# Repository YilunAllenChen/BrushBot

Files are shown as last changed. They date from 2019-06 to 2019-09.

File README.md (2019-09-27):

# BrushBot 2

This Repo serves the BrushBot 2.0 project from its hardware to its software.

## Project Structure
main.py: the program that ESP will execute once it boots up.\
ina219.py: Firmware for ina219 current sensor.\
vl6180Driver.py: Firmware for VL6180x sensor.\
logging.py: Supporting module for ina219 current sensor.\
DRV8836.py: Firmware for DRV8836 motor driver.

## Installation
Before the installation process begins, make sure your BrushBot is connected through FTDI to the computer.

You need to find the port connected to the BrushBot and replace "your_port" in the script below with that port. on Windows it should look like "COMx", mac "dev/xxxxx", linux "USB/ttyx".

Then run the script under the repo directory:

    python install.py your_port

The script provided by this repo will allow you to automatically install the dependencies of computer-brushbot interaction. Afterwards, it will attempt to installing the micropython firmware under the ./_MicroPython_bin directory to the BrushBot connected. This process involves erasing the flash and putting the bin file inside.

Once this is done, you can use the following script to automatically upload all your programs under ./Firmware directory to the robot. The your_port part is the same deal as the one with the install.py script.

    python Upload.py your_port

## INA219 Interface Example

```python
from ina219 import INA219
from machine import I2C

i2c = machine.I2C(-1,machine.Pin(22),machine.Pin(21)) #setup i2c
SHUNT_OHMS = 0.1 # Hardware setup - shunt resistance
ina = INA219(SHUNT_OHMS, i2c) # Create a sensor object
ina.configure() # Default configuration

# Usage
print("Bus Voltage: %.3f V" % ina.voltage())
print("Current: %.3f mA" % ina.current())
print("Power: %.3f mW" % ina.power())
```

## VL6180 Interface Example

```python
import machine
import sys
import utime
import vl6180_Driver

i2c = machine.I2C(-1,machine.Pin(22),machine.Pin(21)) #setup i2
sensor1 = vl6180_Driver.Sensor(i2c,41) # Create a sensor object

# Usage
print("Value read in address 41: " + str(sensor1.range()))
```

## DRV8836 Interface Example

```python
import machine #Required by machine.Pin
import DRV8836

A1 = machine.Pin(33) # Select the four pins used to control
A2 = machine.Pin(25) # the two motors
B1 = machine.Pin(26)
B2 = machine.Pin(27)
drv = DRV8836.DRV8836(A1, A2, B1, B2) # Create the motor driver object

# Usage
drv.testRun() # Test run function.
drv.setLeft(1000) # Set the motor output of left. -1023 ~ 1023.
drv.stop()
```

## TCP-IP
Note: In order for the Controller to work, the server side computer needs to allow TCP/IP inbound/outbound connections on port 23.

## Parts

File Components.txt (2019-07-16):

VL6180	-	Light Sensor
ESP32 -	MCU
AP2112	-	Voltage Regulator / Power supply
BQ24075 -	Wireless Charging
	Choosing charging rates:
		K_ISET values: min/avg/max: 797/890/975
		I_CHG => K_ISET/R_ISET. For example, In order to have a 800mA charge current: 890 / 0.8 = 1.1125kOhm, so connect a 1.13kOhm resistor between ISET(16) and VSS.

	Choosing Limit charge rates:
		K_ILIM values: min/avg/max: 1550/1610/1720 for I_LIM in (0.5A,1.5A), 1330/1525/1720 for I_LIM in (0.2A, 0.5A). I_LIM at pin 12.
		R_ISET = 1550 / 1.3 = 1.192kOhm, so connect a 1.18kOhm resistor between ILIM(12) and VSS.

	Choosing 6.25h safety charging timer:
		R_TMR = t_maxchrg / (10*K_TMR)
		K_TMR = 48 (36/48/60)
		R_TMR = 6.25h * 3600s/h / (10*48) = 46.8kOhm, so connect a 46.4kOhm between TMR(2) and VSS.

INA219 - 	Current Sensor / Power monitoring component

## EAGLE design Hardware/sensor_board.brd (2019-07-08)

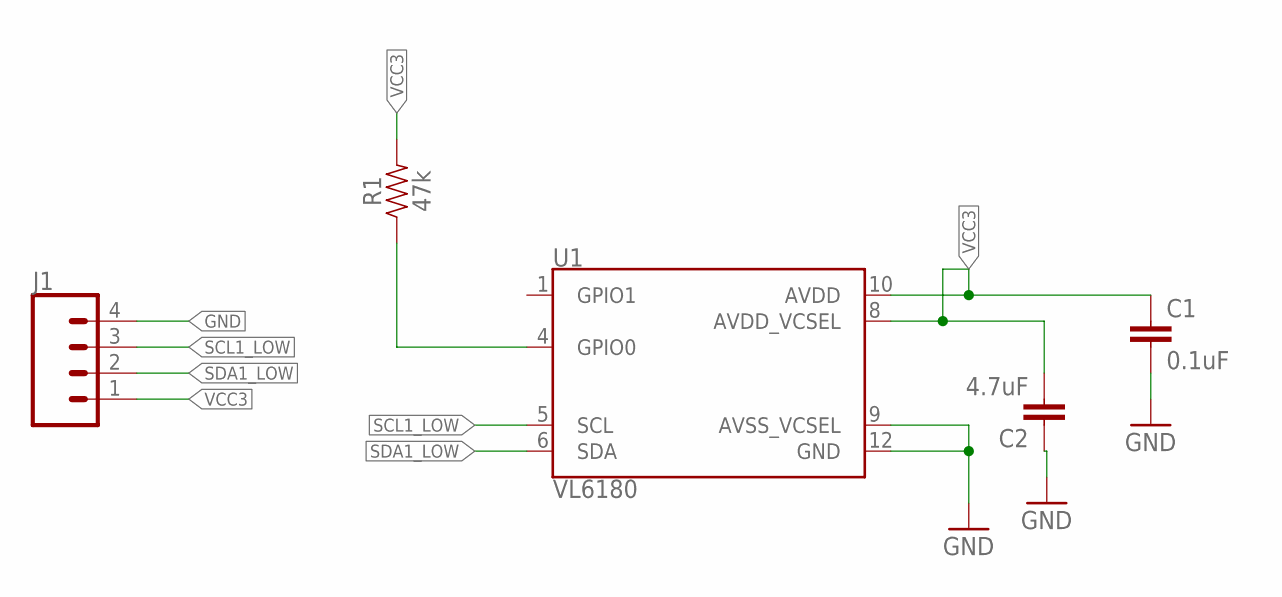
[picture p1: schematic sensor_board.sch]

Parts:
C1: 0.1uF; 0603
C2: 4.7uF; 0603
J1: CONN_04PTH; 1X04
R1: 47k; 0603
U1: VL6180

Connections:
GND: C1.2, C2.1, J1.4, U1.9 (AVSS_VCSEL), U1.12 (GND)
unnamed: R1.1, U1.4 (GPIO0)
SCL1_LOW: J1.3, U1.5 (SCL)
SDA1_LOW: J1.2, U1.6 (SDA)
VCC3: C1.1, C2.2, J1.1, R1.2, U1.8 (AVDD_VCSEL), U1.10 (AVDD)

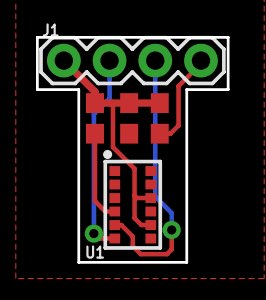
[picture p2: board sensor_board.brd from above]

Board: 2 copper layers, 10.6 x 12.5 mm, 5 parts (0 on the bottom side), 5 nets.

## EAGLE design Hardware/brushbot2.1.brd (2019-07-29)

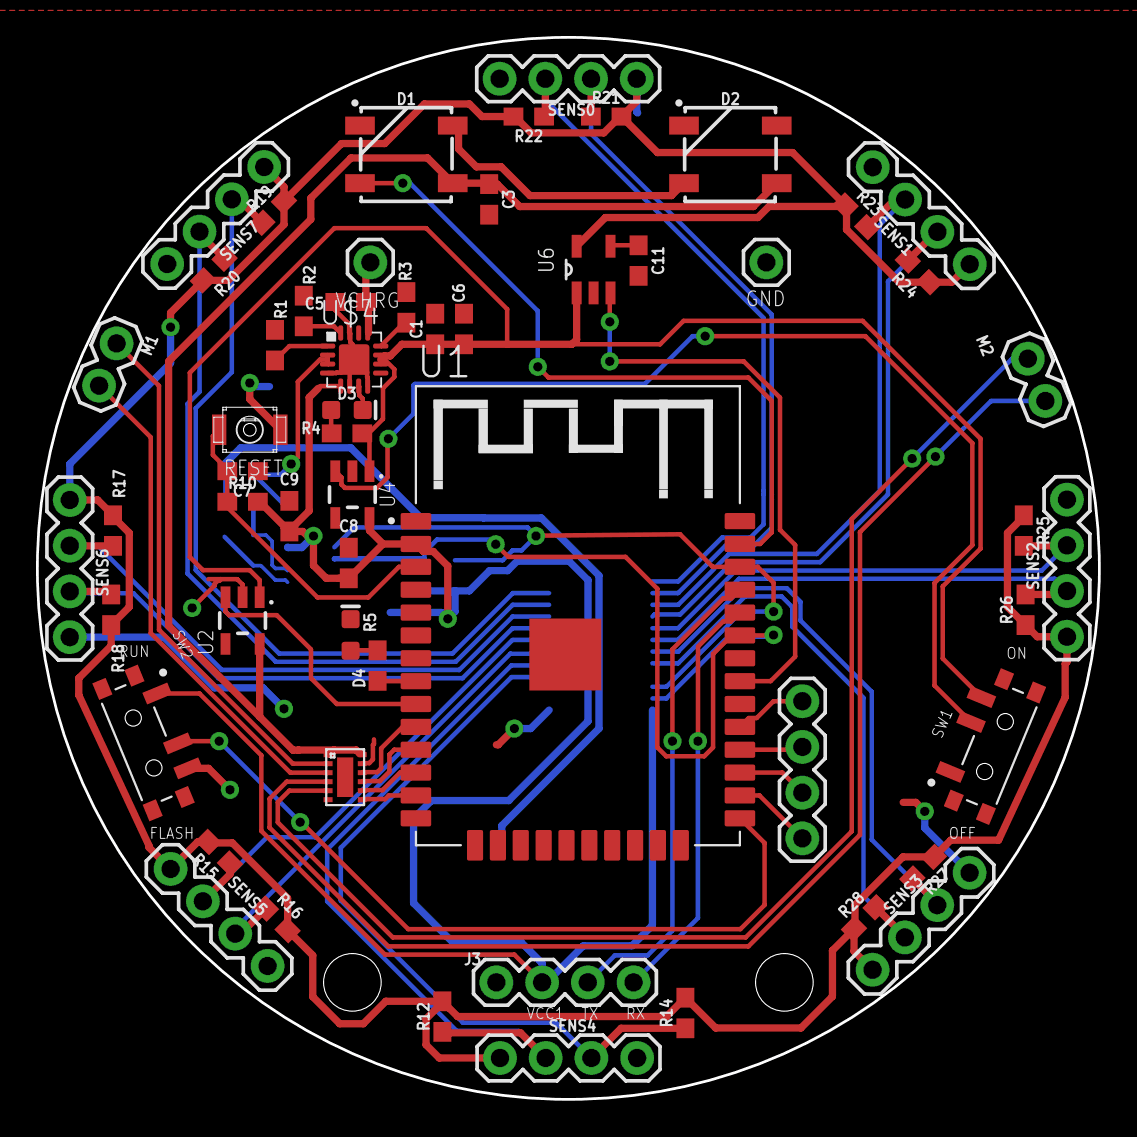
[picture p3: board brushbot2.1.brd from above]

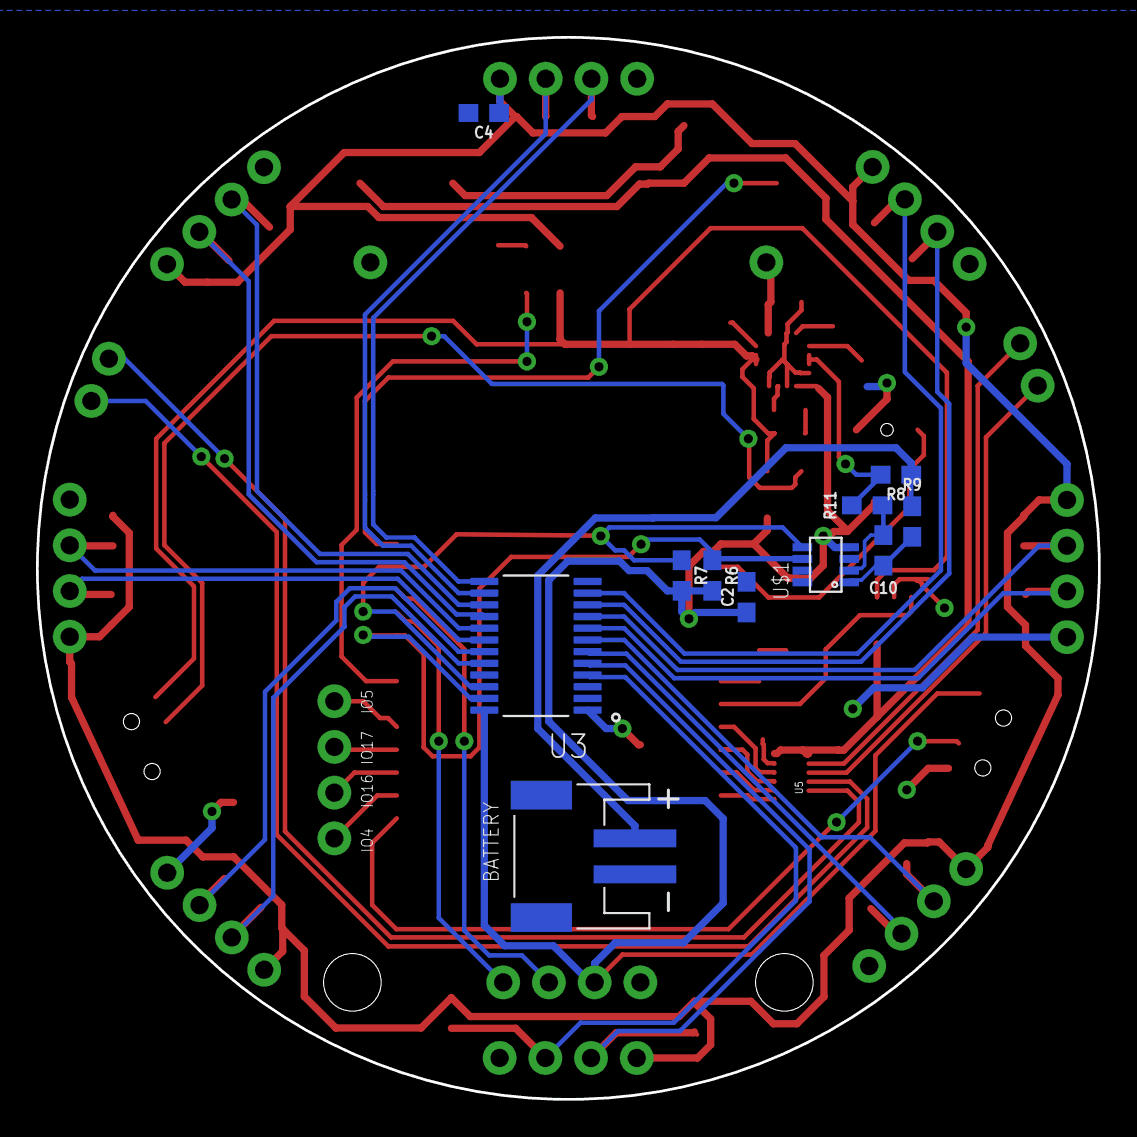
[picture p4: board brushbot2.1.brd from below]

Board: 2 copper layers, 59.0 x 59.0 mm, 69 parts (11 on the bottom side), 57 nets.

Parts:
C1, C2, C3, C5: 1.0uF; 0603
C4: 10uF; 0603
C6: 4.7uF; 0603
C7, C8, C9, C10: 0.1uF; 0603
C11: 10nF; 0603
CN1: JST-PH-2-SMT-RA
D1, D2: WS2812B
D3, D4: RED; LED-0603
FRAME2: FRAME-LEDGER; CREATIVE_COMMONS
J3, J12: 1X04
J4, J5: 1X01
M1, M2: 1X02
R1, R10: 10k; 0603
R2: 1.8k; 0603
R3, R4: 1k; 0603
R5: 47k; 0603
R6, R7, R12, R14, R15, R16, R17, R18, R19, R20, R21, R22, R23, R24, R25, R26, R27, R28: 4.7k; 0603
R8: 0.05; 0603
R9, R11: 10; 0603
RST_BUTTON: BUTTON_TACTILE_SLIM
SENS0, SENS1, SENS2, SENS3, SENS4, SENS5, SENS6, SENS7: 1X04
SW1, SW2: PCM12SMTR; SW_PCM12SMTR
U1: ESP-WROOM-32; MODULE_ESP-WROOM-32
U2, U4: 3.3V; SOT23-5
U3: TCA9548APWR; SOP65P640X120-24N
U5: DRV8836; 12WSON
U6: TPS79328DBVR; SOT95P280X145-5N
U$1: INA219; SOT-23-8
U$4: BQ24075; QFN16

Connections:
26: J12.1, U1.26
27: J12.2, U1.27
28: J12.3, U1.28
29: J12.4, U1.29
AIN1: U1.10, U5.10
AIN2: U1.11, U5.9
BIN1: U1.12, U5.8
BIN2: U1.13, U5.7
GND: C1.2, C2.2, C3.2, C4.2, C5.2, C6.2, C7.1, C8.1, C9.1, C11.2, CN1.2, D1.3, D2.3, D4.C, J3.1, J5.1, R1.1, R2.1, R3.2, RST_BUTTON.2, SENS0.4, SENS1.4, SENS2.4, SENS3.4, SENS4.4, SENS5.4, SENS6.4, SENS7.4, SW1.1, SW2.3, U1.1, U1.1.1, U1.15, U1.38, U2.2, U3.1, U3.2, U3.12, U3.21, U4.2, U5.6, U5.11, U6.2, U$1.3, U$1.7, U$1.8, U$4.4, U$4.6, U$4.8, U$4.15, U$4.TH
GPIO0: SW2.2, U1.25
LED1OUT: D1.2, D2.4
LEDS: D1.4, U1.37
M1+: M1.1, U5.2
M1-: M1.2, U5.3
M2+: M2.1, U5.4
M2-: M2.2, U5.5
MOTOR_EN: U1.9, U2.3
unnamed: R1.2, U$4.1
unnamed: SW1.2, U4.3
unnamed: R2.2, U$4.16
unnamed: R3.1, U$4.12
unnamed: C10.1, R9.2, U$1.1
unnamed: D3.C, U$4.7
unnamed: D3.A, R4.1
unnamed: R5.2, U1.8
unnamed: D4.A, R5.1
unnamed: C10.2, R11.2, U$1.2
unnamed: CN1.1, R8.1, R9.1
unnamed: C11.1, U6.4
RESET: C7.2, R10.1, RST_BUTTON.1, U1.3
SCL1: R7.1, U1.36, U3.22, U$1.5
SCL1_0: R21.1, SENS0.2, U3.14
SCL1_1: R24.2, SENS1.2, U3.16
SCL1_2: R26.2, SENS2.2, U3.18
SCL1_3: R28.2, SENS3.2, U3.20
SCL1_4: R12.1, SENS4.2, U3.5
SCL1_5: R15.1, SENS5.2, U3.7
SCL1_6: R17.1, SENS6.2, U3.9
SCL1_7: R19.1, SENS7.2, U3.11
SDA1: R6.1, U1.33, U3.23, U$1.6
SDA1_0: R22.1, SENS0.3, U3.13
SDA1_1: R23.2, SENS1.3, U3.15
SDA1_2: R25.2, SENS2.3, U3.17
SDA1_3: R27.2, SENS3.3, U3.19
SDA1_4: R14.1, SENS4.3, U3.4
SDA1_5: R16.1, SENS5.3, U3.6
SDA1_6: R18.1, SENS6.3, U3.8
SDA1_7: R20.1, SENS7.3, U3.10
SENS_EN: U1.31, U6.3
U0RX: J3.4, U1.34
U0TX: J3.3, U1.35
VBAT: R8.2, R11.1, U$4.2, U$4.3
VCC1: C2.1, C8.2, C9.2, J3.2, R6.2, R7.2, R10.2, SW2.1, U1.2, U3.24, U4.5, U$1.4, U$4.5
VCC2: C3.1, D1.1, D2.1, U2.5, U5.1, U5.12
VCC3: C4.1, R12.2, R14.2, R15.2, R16.2, R17.2, R18.2, R19.2, R20.2, R21.2, R22.2, R23.1, R24.1, R25.1, R26.1, R27.1, R28.1, SENS0.1, SENS1.1, SENS2.1, SENS3.1, SENS4.1, SENS5.1, SENS6.1, SENS7.1, U6.5
VCHRG: C5.1, J4.1, U$4.13
V_SUP: C1.1, C6.1, R4.2, SW1.3, U2.1, U4.1, U6.1, U$4.10, U$4.11

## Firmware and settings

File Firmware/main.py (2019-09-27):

import machine
import neopixel
import sys
import utime
import vl6180
import DRV8836
import networking
from ina219 import INA219
# from configureVL6180 import configureVL6180   #archived.


############    Initiazation Settings - Don't Change    ######################
print("\nInitializing devices. The red LED on the robot should light up.\n")

# WiFi Connections
try:
    wlan = networking.connect('brushbotarium', 'brushbotrules')
    socket = networking.connect_socket('192.168.1.2')
except:
    print("\033[91m{}\033[00m".format("Failed") + " to connect to hotspot.")



# Default Reset Pin Definition. Don't Change.
repl_button = machine.Pin(0, machine.Pin.IN, machine.Pin.PULL_UP)


# Sensor-enable Initialization
sensor_en = machine.Pin(19, machine.Pin.OUT)
sensor_en.value(0)


# I2C Definition. Don't change.
myi2c = machine.I2C(-1, machine.Pin(22), machine.Pin(21))


# Default LED pin. Bot Running Indicator. This LED is right to the left of the ESP board.
led = machine.Pin(32, machine.Pin.OUT)
led.value(1)


# LED neoPixel on Pin 37 setup
try:
    neoPixel = neopixel.NeoPixel(machine.Pin(23), 2)
    print("\033[92m{}\033[00m" .format(
        "Successfully") + " configured neoPixels")
except:
    print("\033[91m{}\033[00m".format("Failed") + " to configure neoPixels")

utime.sleep(1)


# Laser Sensor Initialization
sensors = []
for addr in range(1, 8):  # VL6180 sensors should be on i2c addresses 41-48.
    try:
        sensors.append(vl6180.Sensor(myi2c))
        print("\033[92m{}\033[00m" .format("Successfully") +
              " configured VL6180x sensor at address " + str(addr))
    except:
        print("\033[91m{}\033[00m".format("Failed") +
              " to initialize VL6180x sensor on i2c address " + str(addr))

utime.sleep(0.2)

# Current Sensor Initialization
shunt_resistance = 0.05      # Change if needed
try:
    ina = INA219(shunt_resistance, myi2c)
    ina.configure()
    print("\033[92m{}\033[00m".format("Successfully") +
          " configured INA219 sensor at address " + str(ina._address))
except:
    print("\033[91m{}\033[00m".format("Failed") +
          " to initialize INA219 sensor on address 65.")

utime.sleep(0.2)

# Motor Driver Initialization
try:
    drv = DRV8836.DRV8836(machine.Pin(33), machine.Pin(25),
                          machine.Pin(26), machine.Pin(27))
    drv.stop()
    motor_en = machine.Pin(18, machine.Pin.OUT)
    motor_en.value(1)
except Exception as e:
    print(e)

# Counter initialization for motor sweep
ticks_max = utime.ticks_add(0, -1)
increment = 100 #increment in PWM
counter = 0
deadline = utime.ticks_add(utime.ticks_ms(),2000)
#utime.sleep(0.2)


####################    End of Initialization   ################################



dataCount = 0

# Blink forever
while True:

    # If button 0 is pressed, drop to REPL
    if repl_button.value() == 0:
        print("Dropping to REPL")
        sys.exit()

    # Display all avaiable I2C addresses
    print("Available addresses: | " + str(myi2c.scan()))

    for ndx in range(len(sensors)):
        try:
            print("Sensor " + str(ndx) + " reading: " +
                  str(sensors[ndx].range()))
        except:
            print("Sensor " + str(ndx) + " doesn't work.")

    # try to print the values given by the current sensor.
    try:
        data = "Bus Voltage: %.3f" % ina.voltage() + "  |  Current: %.3f mA" % ina.current() + "  |  Power: %.3f mW" % ina.power()
        print(data)
        socket.sendall(data.encode())
        dataCount = dataCount + 1
    except:
        print("\033[92m {}\033[00m".format("INA219 sensor is malfunctioning."))

    # Turn LED on and then off
    neoPixel[1] = (0, 0, 10)
    neoPixel[0] = (0, 10, 0)
    neoPixel.write()
    utime.sleep_ms(1000)

    # Motor control
    if utime.ticks_diff(utime.ticks_ms(),deadline) > 0:
        print("Updating Speed" + str(deadline))
        deadline = utime.ticks_add(utime.ticks_ms(),2000)
        counter = counter + 1

    if counter > 10:
        counter = 0

    current_speed = counter*increment
    drv.setLeft(current_speed)
    drv.setRight(current_speed)

    neoPixel[1] = (0, 10, 0)
    neoPixel[0] = (0, 0, 10)
    neoPixel.write()

    #utime.sleep_ms(1000)
    #drv.stop()

    if dataCount >= 10:
        socket.close()

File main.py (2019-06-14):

import machine
import sys
import utime

# Pin definitions
repl_button = machine.Pin(0, machine.Pin.IN, machine.Pin.PULL_UP)

# Wait for button 0 to be pressed, and then exit
while True:

    # If button 0 is pressed, drop to REPL
    if repl_button.value() == 0:
        print("Dropping to REPL")
        sys.exit()

    # Do nothing
    utime.sleep_ms(1)

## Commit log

2019-06-13 adding esp32 firmware bin file and a test python script
2019-06-14 Adding schematics; Fixed main.py
    [brushbot2.0.brd, brushbot2.0.sch]
2019-06-20 main.py updated with i2c enabled. Added vl6180 driver. Updated schematics.
2019-06-20 Removed Early Convergence Time Check
    [brushbot2.0.brd, brushbot2.0.sch]
2019-06-23 updated schematics
    [brushbot2.0.brd, brushbot2.0.sch]
2019-07-02 final board design uploaded
2019-07-08 final PCB layout added
    [brushbot2.0.brd, brushbot2.0.sch, sensor_board.brd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]
2019-07-24 LED configured for custom BrushBot board
    [brushbot2.1.brd, brushbot2.1.sch]
2019-07-29 BrushBot 2.1 board design completed
    [brushbot2.1.brd]
2019-07-30 new DRV8836 driver, cleaned up hardware files
2019-07-30 fixed a bug in VL6180 firmware
    [DRV8836.py, main.py, vl6180.py]
2019-09-27 updates, removed problematic ampy install
    [main.py]

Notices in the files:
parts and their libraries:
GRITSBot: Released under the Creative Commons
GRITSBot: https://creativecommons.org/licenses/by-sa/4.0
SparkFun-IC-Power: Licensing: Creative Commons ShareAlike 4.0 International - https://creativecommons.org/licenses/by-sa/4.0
